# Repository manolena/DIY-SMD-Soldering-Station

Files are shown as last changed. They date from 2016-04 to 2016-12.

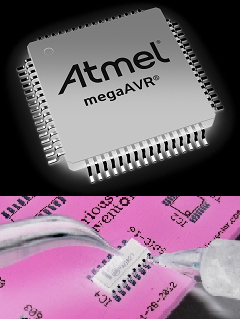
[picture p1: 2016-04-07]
microSD Files/FILE7.bmp

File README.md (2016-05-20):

# DIY-SMD-Soldering-Station
A DIY Soldering Station with ATMega2560 and SMD parts

Many thanks to Matthias <https://debugginglab.wordpress.com/2014/10/30/soldering-station/> for
the inspiration.
There were some improvments to UI with insertion of bargraphs for desired and actual temperature, 
indication for memory saved last desired temperature and settings with rotary endoder instead of
pot.

It would be also a remiss not to thank Stefanos Tselepis FireDeveloper <https://github.com/FireDeveloper> for his
aewosome RGB MultyBit Calculator. It helped a lot for developing code with MCUFRIEND small TFT.

From version IRON_18 and later, the combatible TFT is this:
   http://www.ebay.com/itm/240x320-3-3V-2-4-SPI-TFT-LCD-Touch-Panel-Serial-Port-Module-with-PBC-ILI9341-/171983887298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

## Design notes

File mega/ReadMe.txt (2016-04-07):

For expanding your Arduino's MEGA2560 pins number, you have to copy the file "mega" into your 
C:\arduino-xxx\hardware\arduino\variants directory. Close and re-open the sketch and all changes 
will be energized.

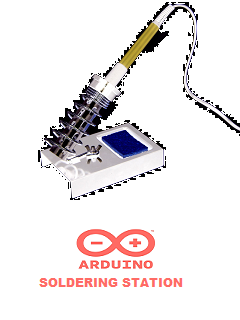
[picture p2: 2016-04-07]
microSD Files/FILE5.bmp

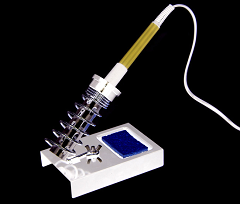
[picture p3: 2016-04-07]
microSD Files/FILE4.bmp

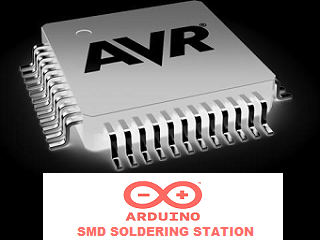
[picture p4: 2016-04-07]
microSD Files/FILE0.bmp

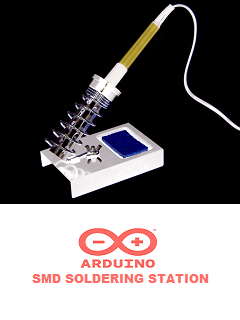
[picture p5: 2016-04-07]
microSD Files/FILE6.bmp

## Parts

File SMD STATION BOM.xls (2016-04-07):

Part List
Source Data From: |  | SMD STATION.PrjPcb
Project: |  | SMD STATION.PrjPcb
Variant: |  | None
Report Date: | 06/04/2016 | 16:29:08
Print Date: | 2016-04-06 | 19:12:58
Designator | Comment | LibRef | Footprint | Description | Link
*1 | HEAT-S1 | HEAT-S1 | SK 104 HEATSHINK |  | http://www.marelectronics.gr/products.php?id=28499&lang=gr
BUZ1 | BUZZER | BUZZER | BUZZER |  | http://www.ebay.com/itm/9mm-Dia-Electronic-Alarm-PCB-Panel-Mounting-Piezo-Buzzer-Sounder-10pcs-/121808580371
C1 | 2200uF/35V | Cap Pol1 | RB5-10.5 | Capacitor, Electrolytic, 2200uF/35V | http://www.acdcshop.gr/capacitorelectrolytic16x25mm105c35v2200uf-p-1131.html?sort=2a
C2, C3, C4, C5, C6 | 100nF | D-101-0085, D-101-0085, Cap, Cap, Cap | 0805 | Capacitor, Ceramic, 100nF 10% 50V 0805 (2012) X7R | http://www.ebay.com/itm/570pcs-57-Value-Kit-0805-SMD-Ceramic-capacitor-1pF-22uF-MLCC-SMT-Assortment-Kit-/161921774228
C7, C8, C9, C10, C11, C14 | 10nF | D-101-0085 | 0805 | Capacitor, Ceramic, 10nF 10% 50V 0805 (2012) X7R | http://www.ebay.com/itm/570pcs-57-Value-Kit-0805-SMD-Ceramic-capacitor-1pF-22uF-MLCC-SMT-Assortment-Kit-/161921774228
C12 | 47nF | D-101-0085 | 0805 | Capacitor, Ceramic, 47nF 10% 50V 0805 (2012) X7R | http://www.ebay.com/itm/570pcs-57-Value-Kit-0805-SMD-Ceramic-capacitor-1pF-22uF-MLCC-SMT-Assortment-Kit-/161921774228
C13 | 10uF/25V | Cap Pol1 | RB-08 | Capacitor, Electrolytic, 10uF/25V | http://www.acdcshop.gr/capacitorelectrolytictht10uf50v2165x11mmpitch2mm20-p-22072.html?sort=2a
D1 | PWR | LED0 | 1206D | LED, Green, 1206 (for PCB), 5mm (for panel) | http://www.ebay.com/itm/120pcs-SMD-SMT-1206-White-Red-Green-Blue-Yellow-Orange-LED-Mix-Super-Bright-Kit-/281638415634
D2 | HEAT | LED0 | 1206D | LED, Red, 1206 (for PCB), 5mm (for panel) | http://www.ebay.com/itm/120pcs-SMD-SMT-1206-White-Red-Green-Blue-Yellow-Orange-LED-Mix-Super-Bright-Kit-/281638415634
J1 | PWR2.5 | PWR2.5 | POWER JACK | Low Voltage Power Supply Connector | http://www.ebay.com/itm/50-pcs-2-Pin-5-5-2-1mm-DC-2-1-SMD-Socket-Jack-Female-PCB-Power-Plug-/251620366426
J2 | PTC+ | CON1_S | CON2 | 5.08mm 2 Pin Connect Terminal Screw Terminal Connector | http://www.banggood.com/20PCS-KF301-2P-5_08mm-2-Pin-Connect-Terminal-Screw-Terminal-Connector-p-1004786.html
J3 | PTC- | CON1_S | CON2 |  | http://www.banggood.com/20PCS-KF301-2P-5_08mm-2-Pin-Connect-Terminal-Screw-Terminal-Connector-p-1004786.html
J4 | + | CON1_S | CON2 | 5.08mm 2 Pin Connect Terminal Screw Terminal Connector | http://www.banggood.com/20PCS-KF301-2P-5_08mm-2-Pin-Connect-Terminal-Screw-Terminal-Connector-p-1004786.html
J5 | STBY_SW | CON1_S | CON2 |  | http://www.banggood.com/20PCS-KF301-2P-5_08mm-2-Pin-Connect-Terminal-Screw-Terminal-Connector-p-1004786.html
J6 | - | CON1_S | CON2 | 5.08mm 2 Pin Connect Terminal Screw Terminal Connector | http://www.banggood.com/20PCS-KF301-2P-5_08mm-2-Pin-Connect-Terminal-Screw-Terminal-Connector-p-1004786.html
J7 | GND | CON1_S | CON2 |  | http://www.banggood.com/20PCS-KF301-2P-5_08mm-2-Pin-Connect-Terminal-Screw-Terminal-Connector-p-1004786.html
J8 | -LED HEAT | CON1_S | CON2 | 5.08mm 2 Pin Connect Terminal Screw Terminal Connector | http://www.banggood.com/20PCS-KF301-2P-5_08mm-2-Pin-Connect-Terminal-Screw-Terminal-Connector-p-1004786.html
J9 | +LED HEAT | CON1_S | CON2 |  | http://www.banggood.com/20PCS-KF301-2P-5_08mm-2-Pin-Connect-Terminal-Screw-Terminal-Connector-p-1004786.html
J10 | +PWR | CON1_S | CON2 | 5.08mm 2 Pin Connect Terminal Screw Terminal Connector | http://www.banggood.com/20PCS-KF301-2P-5_08mm-2-Pin-Connect-Terminal-Screw-Terminal-Connector-p-1004786.html
J11 | -PWR | CON1_S | CON2 |  | http://www.banggood.com/20PCS-KF301-2P-5_08mm-2-Pin-Connect-Terminal-Screw-Terminal-Connector-p-1004786.html
J12, J13 | K-TC | CON1_S | CON2 | 5.08mm 2 Pin Connect Terminal Screw Terminal Connector | http://www.banggood.com/20PCS-KF301-2P-5_08mm-2-Pin-Connect-Terminal-Screw-Terminal-Connector-p-1004786.html
J14, J15 | NTC | CON1_S | CON2 |  | http://www.banggood.com/20PCS-KF301-2P-5_08mm-2-Pin-Connect-Terminal-Screw-Terminal-Connector-p-1004786.html
MD1 | ATMEGA2860 CORE | ATMEGA2560 CORE | ATMEGA 2560 CORE | Mega2560-CORE mini 2560 Arduino | http://www.ebay.com/itm/221502571388
MDL1, MDL2 | STEP DOWN CONVERTER | STEP DOWN CONVERTER | STEP DOWN CONVERTER MINI | Mini DC Adjustable Power Supply Buck Module Step Down Module | http://www.banggood.com/5Pcs-Mini-DC-Adjustable-Power-Supply-Buck-Module-Step-Down-Module-p-952402.html
OP1 | TCMT1100 | OPTO-AC1 | SOP-4 | AC OPTOCUPLER | http://www.ebay.com/itm/30-St-SMD-Optokoppler-TCMT-1100-Vishay-E0671-/400690570408
P1 | ISP | Header 3X2 | HDR2X3 | Header, 3-Pin, Dual row | http://www.ebay.com/itm/10PCS-2-54mm-2-x-40-Pin-Male-Double-Row-Pin-Header-Strip-/130713472733
P2, P3 | Header 13X2 | Header 13X2 | IDC2.54-V26A | Header, 13-Pin, Dual row | http://www.ebay.com/itm/10PCS-2-54mm-2-x-40-Pin-Male-Double-Row-Pin-Header-Strip-/130713472733
Q1 | IRF9530 | PMOS-2 | TO-220V | P-Channel Power MOSFET | http://www.acdcshop.gr/transistorunipolarpmosfet100v12a88wto220ab-p-13376.html?sort=2a
Q2 | BS170 | NMOS-2 | T0-92 | N-Channel Power MOSFET | http://www.ebay.com/itm/10PCS-BS170-MOSFET-N-CH-60V-500MA-TO-92-FSC-NEW-/141739738318
Q3 | MMBTA42 | NPN | SO-G3 | NPN Bipolar Transistor | http://www.ebay.com/itm/100PCS-IC-MMBTA42-SOT-23-TRANSISTOR-NPN-300V-0-5A-Pb-Free-RoHS-SMD-/171538574109
Q4 | MMBTA92 | PNP | SO-G3 | PNP Bipolar Transistor | http://www.ebay.com/itm/100PCS-IC-MMBTA92-SOT-23-TRANSISTOR-NPN-300V-0-5A-Pb-Free-RoHS-SMD-/181583143545
R1, R5, R11, R12, R17 | 1K | Res2, RES, Res2, RES, RES | 0805 | Resistor, Ceramic, 1%, 0805 | http://www.ebay.com/itm/80-Value-0805-SMD-Resistor-Kit-1-10R-910K-80valuesX25pcs-2000pcs-/121614392100
R2, R3, R4, R16, R19 | 10K | RES, Res2, RES, RES, RES | 0805 |  | http://www.ebay.com/itm/80-Value-0805-SMD-Resistor-Kit-1-10R-910K-80valuesX25pcs-2000pcs-/121614392100
R6 | 220K | RES | 0805 |  | http://www.ebay.com/itm/80-Value-0805-SMD-Resistor-Kit-1-10R-910K-80valuesX25pcs-2000pcs-/121614392100
R7 | 220R | Res2 | 0805 |  | http://www.ebay.com/itm/80-Value-0805-SMD-Resistor-Kit-1-10R-910K-80valuesX25pcs-2000pcs-/121614392100
R8 | 15K | RES | 0805 |  | http://www.ebay.com/itm/80-Value-0805-SMD-Resistor-Kit-1-10R-910K-80valuesX25pcs-2000pcs-/121614392100
R9 | 2K2 | RES | 0805 |  | http://www.ebay.com/itm/80-Value-0805-SMD-Resistor-Kit-1-10R-910K-80valuesX25pcs-2000pcs-/121614392100
R10 | 330R | RES | 0805 |  | http://www.ebay.com/itm/80-Value-0805-SMD-Resistor-Kit-1-10R-910K-80valuesX25pcs-2000pcs-/121614392100
R13 | 4K7 | RES | 0805 |  | http://www.ebay.com/itm/80-Value-0805-SMD-Resistor-Kit-1-10R-910K-80valuesX25pcs-2000pcs-/121614392100
R14, R20 | 100K/1% | RES | 0805 |  | http://www.ebay.com/itm/80-Value-0805-SMD-Resistor-Kit-1-10R-910K-80valuesX25pcs-2000pcs-/121614392100
R15, R18 | 24K/1% | RES | 0805 |  | http://www.ebay.com/itm/80-Value-0805-SMD-Resistor-Kit-1-10R-910K-80valuesX25pcs-2000pcs-/121614392100
R21 | 10K/1% | RES | 0805 |  | http://www.ebay.com/itm/80-Value-0805-SMD-Resistor-Kit-1-10R-910K-80valuesX25pcs-2000pcs-/121614392100
R22 | 5K | RPot2 | VR6 | 3296W Multiturn Trimmer Resistance Potentiometer Kit | http://www.banggood.com/50Pcs-3296W-Multiturn-Trimmer-Resistance-Potentiometer-Kit-p-969193.html
R23 | 120K | RES | 0805 | 'Resistor, Ceramic, 1%, 0805 | http://www.ebay.com/itm/80-Value-0805-SMD-Resistor-Kit-1-10R-910K-80valuesX25pcs-2000pcs-/121614392100
R24 | 100K | RPot2 | VR6 | 3296W Multiturn Trimmer Resistance Potentiometer Kit | http://www.banggood.com/50Pcs-3296W-Multiturn-Trimmer-Resistance-Potentiometer-Kit-p-969193.html
S1 | SW-SPST | SW-SPST | SPST-2 | Single-Pole, Single-Throw Switch | http://www.acdcshop.gr/switchtoggle2positionspdtonon3a250vac5524785c20m-p-21899.html
S2 | SW DIP-4 | SW DIP-4 | DIP-8 | DIP Switch, 4 Position, SPST | http://www.acdcshop.gr/switchdipswitchpolesnumber4onoff01a24vdc2524770c-p-19100.html
SW1 | ENCODER | ROTARY ENC | HDR1X5 |  | http://www.banggood.com/5Pcs-5V-KY-040-Rotary-Encoder-Module-For-Arduino-AVR-PIC-p-951151.html
TFT1 | 2.4 | 2.4 TFT SHIELD MCUFRIEND | ARDUINO UNO |  | http://www.banggood.com/UNO-R3-ATmega328P-Board-2_4-Inch-TFT-LCD-Screen-Module-For-Arduino-p-945755.html
U1, U2 | LT1013 | LT1013ACJ8 | DIP-8 | Dual Precision Operational Amplifier | http://www.acdcshop.gr/operationalamplifierdip8-p-24732.html?sort=2a
U3 | LM336 | LM336Z | Z03A | Adjustable Micropower Voltage Reference | http://www.marelectronics.gr/products.php?id=2545&lang=gr
 |  |  |  | Soldering Iron Gun Hot Iron Replacement Solder Station Repair Tool | http://www.banggood.com/Soldering-Iron-Gun-Hot-Iron-Replacement-Solder-Station-Repair-Tool-p-87173.html
 |  |  |  | Κουτί Τροφοδοτικού - Enclosure ABS for power supply 190x110x75 snapsScrews | http://www.acdcshop.gr/enclosureabsforpowersupply190x110x75snapsscrews-p-7487.html

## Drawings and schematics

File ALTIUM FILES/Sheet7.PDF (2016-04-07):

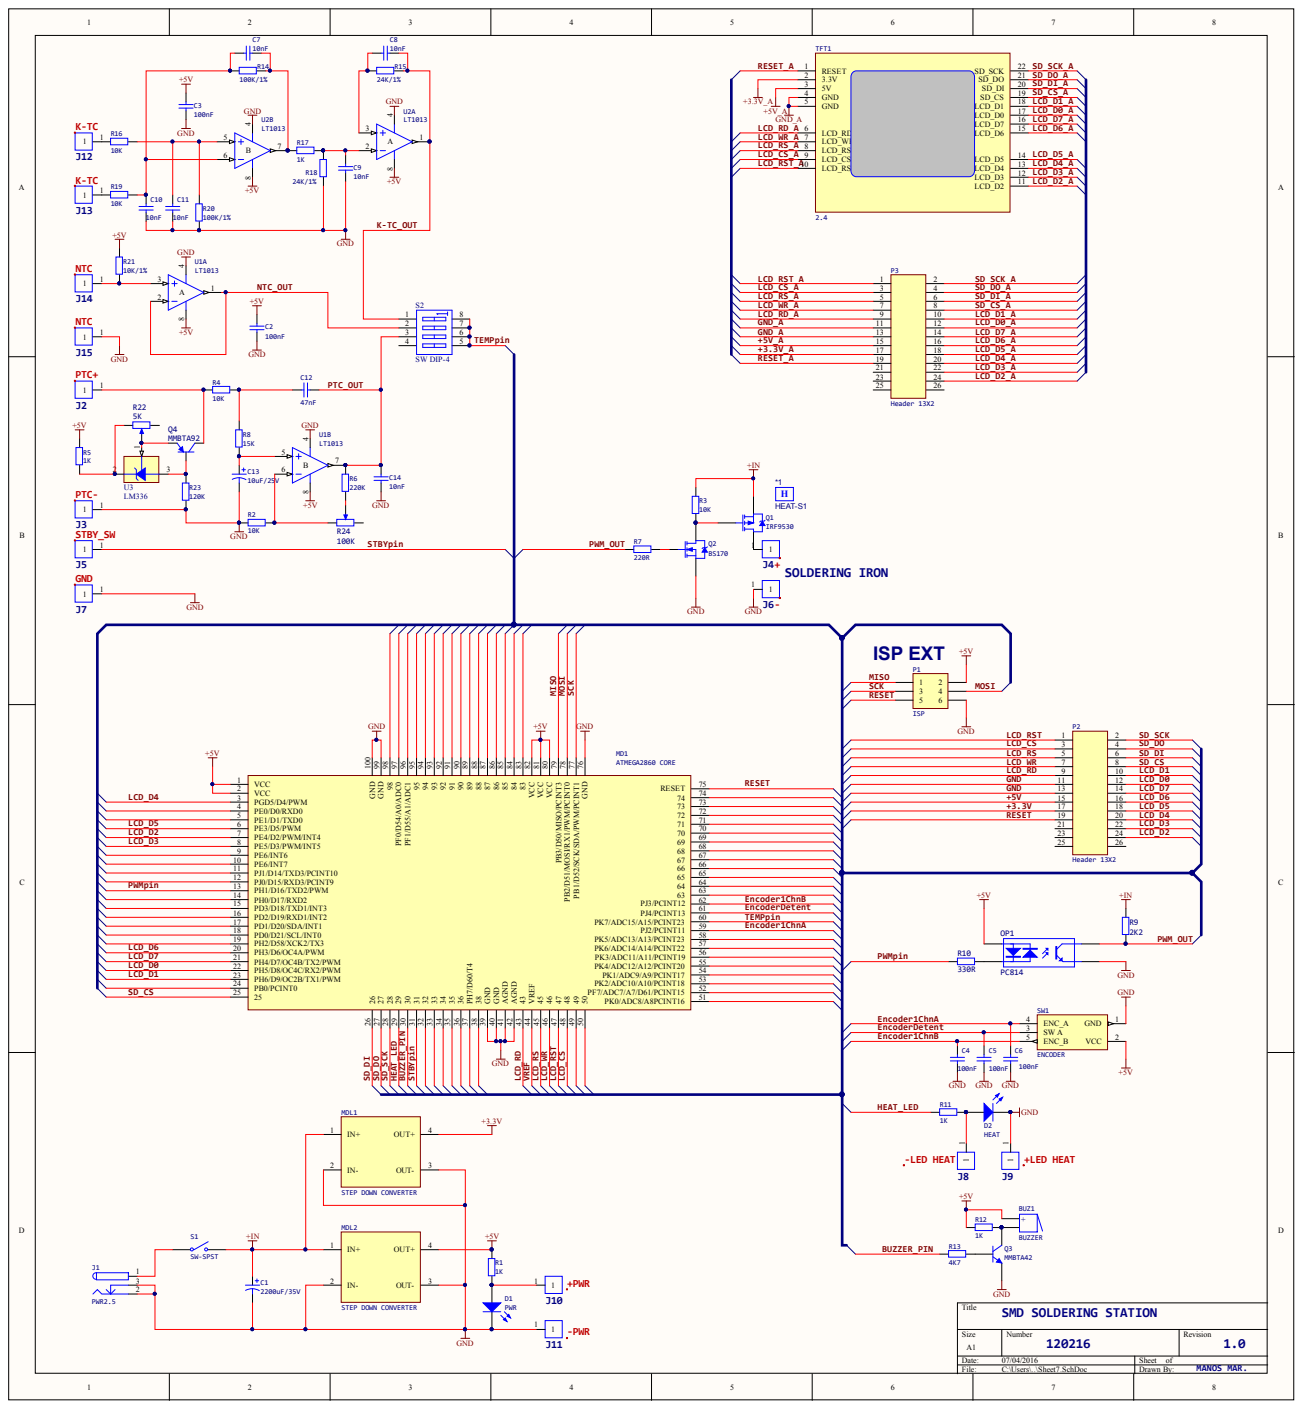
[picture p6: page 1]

GND 76 PB1/D52/SCK/SDA/PWM/PCINT1 77 PB2/D51/MOSI/RX1/PWM/PCINT0 78 PB3/D50/MISO/PCINT3 79 VCC 80 VCC 81 VCC 82 83 83 84 84 85 85 86 86 87 87 88 88 89 89 90 90 91 91 92 92 93 93 94 94 95 95 PF1/D55/A1/ADC1 96 PF0/D54/A0/ADC0 97 98 98 GND 99 GND 100

Date: 07/04/2016 | Sheet of
File: C:\Users\..\Sheet7.SchDoc | Drawn By: MANOS MAR.

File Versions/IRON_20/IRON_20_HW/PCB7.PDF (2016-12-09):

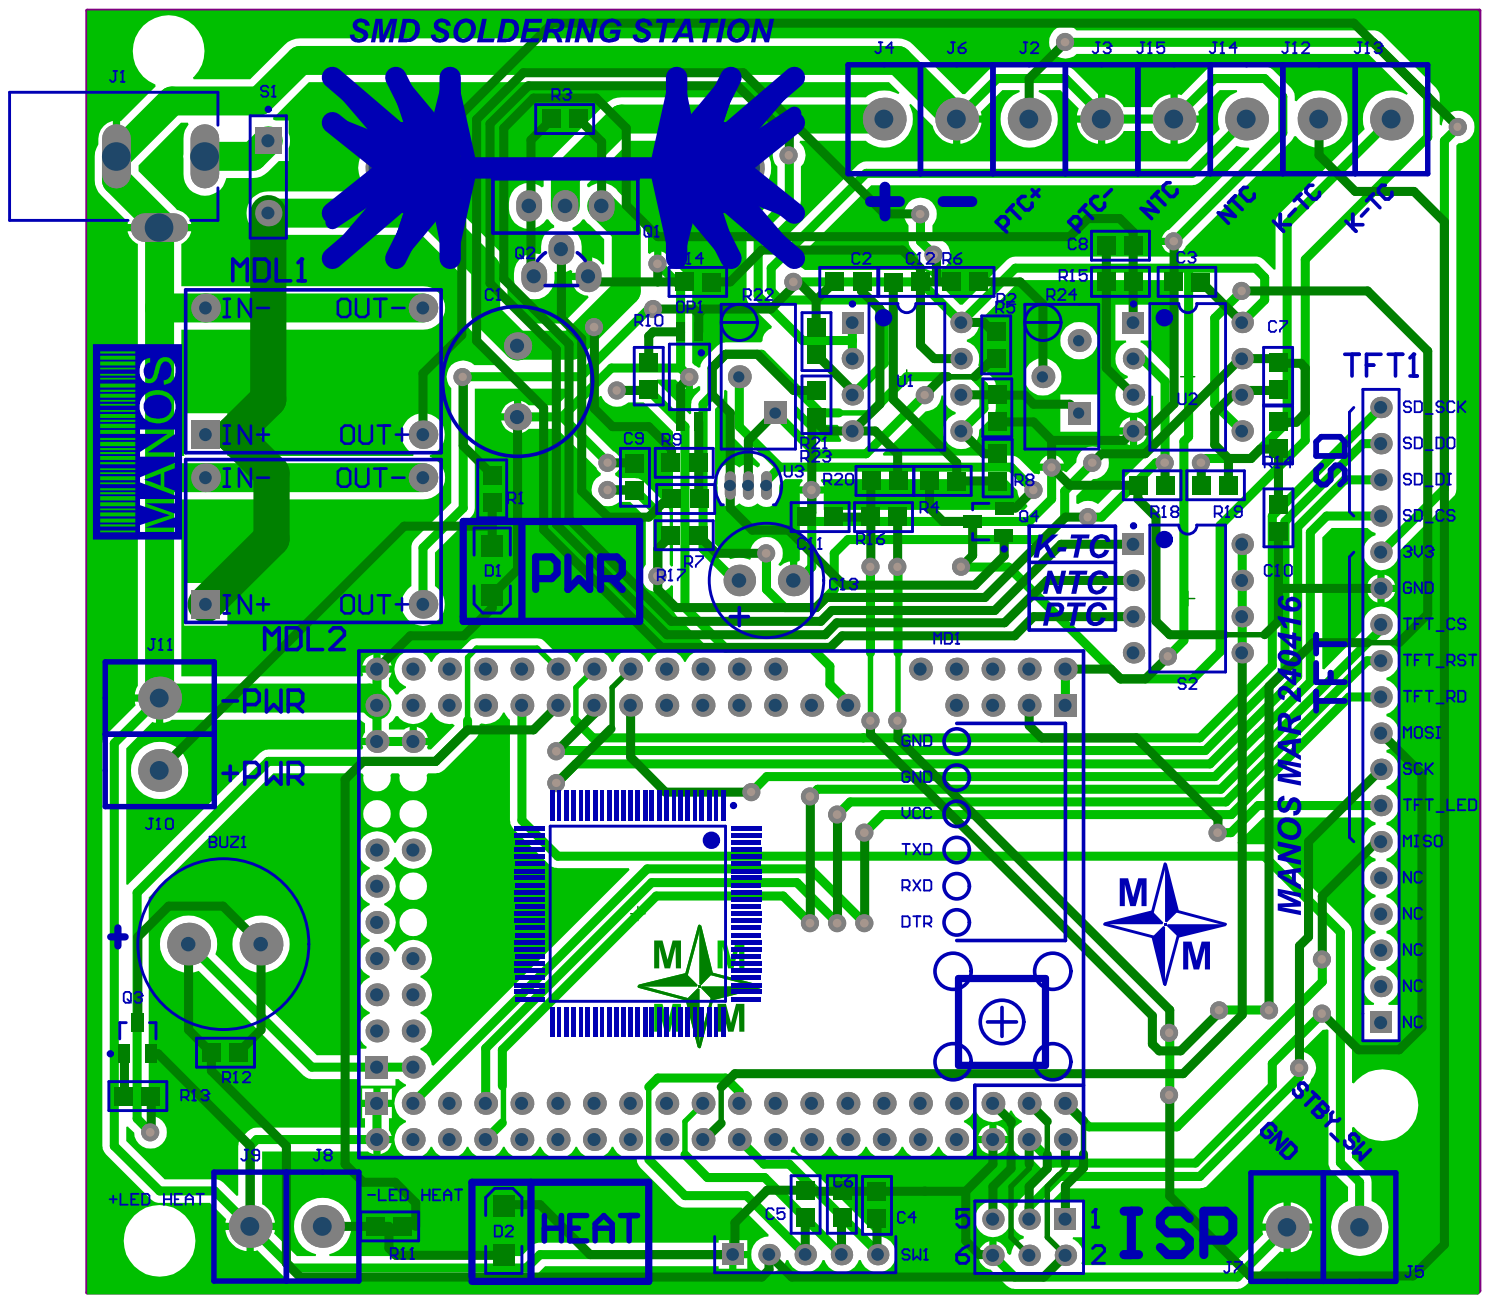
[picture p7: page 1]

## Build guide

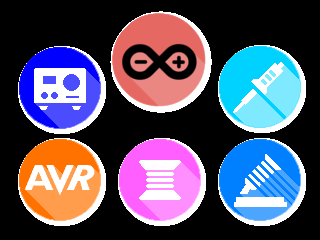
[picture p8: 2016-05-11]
microSD Files/SolderingStation2.bmp

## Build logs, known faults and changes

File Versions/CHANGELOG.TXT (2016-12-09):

11APR2016: The latest version is now IRON_18 and firmware version is 1.5

1. Added iron holder with in-built "Iron in parking position" capability. The actual temperature automatically drops 
    down to 175°C if desired temperature is > 175°C and the iron is in parking position.
2. Added "unplugged iron" function: when device is unplugged, a message appears on the screen until it is plugged
    back again.
3. Added "click sound" when encoder is rotating.    
4. Combatible TFT for this version is this: 
   http://www.ebay.com/itm/240x320-3-3V-2-4-SPI-TFT-LCD-Touch-Panel-Serial-Port-Module-with-PBC-ILI9341-/171983887298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
   
09DEC2016: The latest version is now IRON_20 and firmware version is 1.6
1. Added backlight for TFT on D4

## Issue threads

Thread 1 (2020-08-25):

DIY-SMD-焊接台

JHS1211, 2020-08-25:
Hello, this soldering station is gorgeous, ask you a question, the soldering station can connect JBC - T245 heater? If you can, how to connect? Thank you very much.

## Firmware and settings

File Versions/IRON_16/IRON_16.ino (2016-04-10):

#include <Adafruit_GFX.h>    // Core graphics library
#include <Adafruit_TFTLCD.h> // Hardware-specific library
#include <SPI.h>
#include <SD.h>
#include <EEPROMEx.h>
#include <Encoder1.h>
#include <PinChangeInt.h>
#include <TimerOne.h>
#include <PID_v1.h>
//=======================================================================
#define MCUFRIENT_2_4_TFT  0x9341

#if defined (__AVR_ATmega2560__) || (__AVR_ATmega1280__)
#define SD_CS                 10     // Set the chip select line to whatever you use (10 doesnt conflict with the library)
#define SD_SCK                13
#define SD_MISO               12
#define SD_MOSI               11
#endif

#define LCD_CS                A3 // Chip Select goes to Analog 3
#define LCD_CD                A2 // Command/Data goes to Analog 2
#define LCD_WR                A1 // LCD Write goes to Analog 1
#define LCD_RD                A0 // LCD Read goes to Analog 0
#define LCD_RESET             A4 // Can alternately just connect to Arduino's reset pin

#define STANDBYin             47
#define TEMPin 	              A15
#define PWMpin 	              16

#define Encoder1ChnA          78
#define Encoder1ChnB          77
#define EncoderDetent         79

#define BUZZER_PIN            48
#define HEAT_LED              49

#define OFF		      0
#define ON		      1


// 16-bit color values:
#define BLACK           0x0000      /*   0,   0,   0 */
#define NAVY            0xFFF0      /*   0,   0, 128 */
#define DARKGREEN       0xFC1F      /*   0, 128,   0 */
#define DARKCYAN        0xFC10      /*   0, 128, 128 */
#define MAROON          0x7800      /* 128,   0,   0 */
#define PURPLE          0x780F      /* 128,   0, 128 */
#define OLIVE           0x7BE0      /* 128, 128,   0 */
#define LIGHTGREY       0xC618      /* 192, 192, 192 */
#define DARKGREY        0x7BEF      /* 128, 128, 128 */
#define BLUE            0x001F      /*   0,   0, 255 */
#define GREEN           0x07E0      /*   0, 255,   0 */
#define CYAN            0x07FF      /*   0, 255, 255 */
#define RED             0xF800      /* 255,   0,   0 */
#define MAGENTA         0xF81F      /* 255,   0, 255 */
#define YELLOW          0x07FF      /* 255, 255,   0 */
#define WHITE           0xFFFF      /* 255, 255, 255 */
#define ORANGE          0xFD20      /* 255, 165,   0 */
#define GREENYELLOW     0xAFE5      /* 173, 255,  47 */
#define PINK            0xF81F

#define ANGLE_0    0
#define ANGLE_90   1
#define ANGLE_180  2
#define ANGLE_270  3

#define VERSION "v1.5"		
#define INTRO

#define DELAY_MAIN_LOOP 	500//150
#define DELAY_MEASURE 		2

#define ADC_TO_TEMP_GAIN 	1.8//0.99//2.50//0.53 //0.415
#define ADC_TO_TEMP_OFFSET      25.0
#define STANDBY_TEMP		175
#define MAX_TEMP		400
#define MIN_TEMP	        25 // Minimum setpoint temperature

#define MAX_PWM_LOW		180//180
#define MAX_PWM_HI		220//210		

#define PWM_DIV                 1024		

#define WILL_TEMP_EEPROM_ADDRESS 0x10
#define ENCODER_EEPROM_ADDRESS   0x20

// Auto turn-off time (in milliseconds)
#define TURN_OFF_TIME 1800000    //30min  1800000

//#define DEBUG_SER
#define BARGRAPHS

double Setpoint, Input, Output;

//Define the aggressive and conservative Tuning Parameters
//double aggKp=0.5, aggKi=0.9, aggKd=0.2;
//double consKp=0.5, consKi=0.9, consKd=0.2;


double aggKp=450, aggKi=260, aggKd=200;
double consKp=450, consKi=260, consKd=200;

//=======================================================================
int pwm = 0; //pwm Out Val 0.. 255
int actual_temperature, will_temp = STANDBY_TEMP;

boolean standby_act = false;
int tempDIV;
float encoderValue = 0;
volatile float encoderPos = 0;
volatile float encoderPosTemp = 0;
volatile boolean PastA = 0;
volatile boolean PastB = 0;
boolean memWrite = false;
boolean memNoWrite = true;
boolean state = false;
boolean heater = false;
boolean unplug = 0;
int t1,t2;
static boolean rotating = false;
const int numReadings = 150;//30
int readings[numReadings];      // the readings from the analog input
int readIndex = 0;              // the index of the current reading
int total = 0;                  // the running total
float adcValue;

long update_last, on_time = 0;
char heater_mode = OFF;

//=======================================================================
Adafruit_TFTLCD tft(LCD_CS, LCD_CD, LCD_WR, LCD_RD, LCD_RESET);
Encoder1 myEncoder = Encoder1(Encoder1ChnA,Encoder1ChnB,EncoderDetent);
PID myPID(&Input, &Output, &Setpoint, consKp, consKi, consKd, DIRECT);
//=======================================================================
void setup(void) 
{ 
  Serial.begin(9600); 
  pinMode(PWMpin, OUTPUT);
  setPwmFrequency(PWMpin, PWM_DIV);
  digitalWrite(PWMpin, HIGH); 
  for (int thisReading = 0; thisReading < numReadings; thisReading++) 
  {
    readings[thisReading] = 0;
  }  
  tft.reset();
  tft.begin(MCUFRIENT_2_4_TFT);
  tft.setRotation(ANGLE_270);//
  Serial.println(F("TFT Reset."));
  delay(10);

  pinMode(STANDBYin, INPUT_PULLUP);

  pinMode(TEMPin, INPUT);
  digitalWrite(TEMPin, LOW);  

  pinMode(BUZZER_PIN, OUTPUT);
  digitalWrite(BUZZER_PIN, LOW); 
  beepBuzzer(6250,250);  

  pinMode(HEAT_LED, OUTPUT);
  digitalWrite(HEAT_LED, LOW);   

  pinMode(Encoder1ChnA, INPUT); 
  digitalWrite(Encoder1ChnA, HIGH); //turn pullup resistor on
  pinMode(Encoder1ChnB, INPUT); 
  digitalWrite(Encoder1ChnB, HIGH); //turn pullup resistor on
  pinMode(EncoderDetent, INPUT); 
  digitalWrite(EncoderDetent, HIGH); //turn pullup resistor on 

  PCintPort::attachInterrupt(Encoder1ChnA, &updateEncoder_ISR, CHANGE); 
  PCintPort::attachInterrupt(Encoder1ChnB, &updateEncoder_ISR, CHANGE);
  PCintPort::attachInterrupt(EncoderDetent, &EncoderClick_ISR, FALLING);
  myEncoder.setRate(1.0f);
  myEncoder.setMinMax(MIN_TEMP,MAX_TEMP); 

  Timer1.initialize(150000); // set a timer of length 100000 microseconds (or 0.1 sec - or 10Hz => the led will blink 5 times, 5 cycles of on-and-off, per second)
  Timer1.attachInterrupt( timer1_ISR ); // attach the service routine here  

  Serial.println(F("Initializing SD card..."));
#if defined (__AVR_ATmega2560__) || (__AVR_ATmega1280__)
  if (!SD.begin(SD_CS, SD_MOSI, SD_MISO, SD_SCK )) 
  {
    Serial.println(F("Initialization failed!"));
    return;
  }
#else
  if (!SD.begin(SD_CS)) 
  {
    Serial.println(F("Initialization failed!"));
    return;
  }
#endif

  Serial.println("Sketch'es location:");
  Serial.println("C:\\Users\\Administrator\\Documents\\DXP\\AVR SOLDERING IRON\\FIRMWARE\\IRON_15");

  Serial.println(F("Initialization done."));
  delay(500);

  SPI.setClockDivider(SPI_CLOCK_DIV4);  // 4MHz 

  tft.fillScreen(tft.color565(255,255,255));//BLACK  
  //  bmpDraw("FILE0.bmp", 0, 0);
  //  delay(2000);

  mainScreen();  

  will_temp = EEPROM.readInt(WILL_TEMP_EEPROM_ADDRESS);
  myEncoder.setPosition(will_temp);

  if (will_temp == 4294967295) 
  {
    will_temp = STANDBY_TEMP;
  }
  encoderPos = EEPROM.readInt(ENCODER_EEPROM_ADDRESS);
  if (encoderPos == 4294967295) 
  {    
    myEncoder.setPosition(will_temp);
  }
  actual_temperature = will_temp;
  //  myEncoder.setPosition(MAX_TEMP-2);
  //  encoderPos = MAX_TEMP-2;
#if defined BARGRAPHS  
  verticalBar();
  horizontalBar();
#endif 
  Input = getTemperature()-ADC_TO_TEMP_OFFSET;
  Setpoint = ADC_TO_TEMP_OFFSET;
  myPID.SetMode(AUTOMATIC);
  heater_mode = ON;
  pwm = 0;
}
//=======================================================================
void mainScreen ()
{
  tft.fillScreen(tft.color565(255,255,255));//BLACK    
  tft.setTextSize(2);
  tft.setTextColor(tft.color565(0,255,255));//RED
  tft.setCursor(260,5);
  tft.print(VERSION);
  tft.setTextColor(tft.color565(255,255,0));//BLUE
  tft.setCursor(258,3);
  tft.print(VERSION);

  tft.setTextColor(BLACK);
  tft.setTextSize(2);
  tft.setCursor(3,57);
  tft.print("TIP");
  tft.setCursor(3,78);
  tft.print("TEMP:");
  tft.setCursor(228,28);
  tft.setTextColor(tft.color565(tempDIV, tempDIV-255, 255-tempDIV));
  tft.print("o");

  tft.setTextColor(tft.color565(255,0,255));
  tft.setCursor(3,143);
  tft.print("SET:");
  tft.setCursor(228,93);
  tft.print("o");

  tft.setTextColor(tft.color565(0,255,255));
  tft.setCursor(3,183);
  tft.print("PWM:");
  tft.setCursor(228,183);
  tft.print("%"); 

  int tempWill = EEPROM.readInt(WILL_TEMP_EEPROM_ADDRESS);
  myEncoder.setPosition(tempWill);
  tft.setTextColor(tft.color565(255,0,255));  //GREEN  
  tft.setTextSize(2);
  tft.setCursor(100,7);
  tft.print("*MEM = ");
  tft.print(tempWill);
  tft.setTextSize(1);
  tft.print(" o"); 
  tft.setTextSize(2);
  tft.print("C    "); 
#if defined BARGRAPHS  
  verticalBar();
  horizontalBar();
#endif   
}  
//=======================================================================
void loop()
{  
  int MAX_PWM;
  // Automatic turn-off
  if((millis() - on_time) >= TURN_OFF_TIME) 
  {
    tft.fillScreen(tft.color565(255,255,255));//BLACK
    heater_mode = OFF;   
    do
    {        
      analogWrite(PWMpin, 0);
      pwm = 0;
      tft.setTextColor(tft.color565(0,255,255));
      tft.setTextSize(5);
      tft.setCursor(5,80);
      tft.print("SHUT DOWN!");
      heater = LOW;
    }
    while(heater_mode == OFF);
    mainScreen();   
  }

  Input = getTemperature()-ADC_TO_TEMP_OFFSET;
  Setpoint = encoderPos;
  double gap = abs(Setpoint-Input); //distance away from setpoint
  if(gap < 10)
  {  //we're close to setpoint, use conservative tuning parameters
    myPID.SetTunings(consKp, consKi, consKd);
  }
  else
  {
    //we're far from setpoint, use aggressive tuning parameters
    myPID.SetTunings(aggKp, aggKi, aggKd);
  }
  myPID.Compute();
  
  pwm = Output;
  MAX_PWM = actual_temperature <= STANDBY_TEMP ? MAX_PWM_LOW : MAX_PWM_HI;
  pwm = pwm > MAX_PWM ? pwm = MAX_PWM : pwm < 0 ? pwm = 0 : pwm;
  analogWrite(PWMpin, pwm);

  if(pwm != 0)
  {
    heater = HIGH;
    tft.fillCircle(150, 190, 11, tft.color565(0,255,255));
  }
  else 
  {    
    heater = LOW;
    tft.fillCircle(150, 190, 11, tft.color565(255,255,255));
  }   
  writeHEATING(will_temp, Input, pwm);
  //delay(DELAY_MAIN_LOOP);		//wait for some time  

  static boolean oneTime = false; 

  will_temp = map(encoderPos, MIN_TEMP, MAX_TEMP, MIN_TEMP, MAX_TEMP);

  int tempWill = EEPROM.readInt(WILL_TEMP_EEPROM_ADDRESS);
  tft.setTextSize(3);  

  if (digitalRead(STANDBYin) == true)
  {
    tft.setCursor(2,2);
    if(oneTime)
    {      
      tft.fillRect(2, 2, 80, 40, tft.color565(255,255,255));
      beepBuzzer(6250,80);
      oneTime = false; 
    }     
    tft.setTextColor(tft.color565(255,0,255));//GREEN
    tft.print("OPP ");
  }  
  else
  {
    tft.setCursor(2,2);
    if(!oneTime)
    {
      tft.fillRect(2, 2, 80, 40, tft.color565(255,255,255));
      beepBuzzer(6250,80);
      oneTime = true;
    }
    tft.setTextColor(tft.color565(0,255,255));
    tft.print("STBY");
  }

  if((memNoWrite == true) && (memWrite = false))
  {    
    tft.setTextColor(tft.color565(255,255,255));    
    memNoWrite = true; 
    memWrite = false; 
  }  
  else if((memNoWrite == false) && (memWrite = true))
  {
    tft.fillRect(90, 2, 170, 20, tft.color565(255,255,255));
    tft.setTextColor(tft.color565(255,0,255));  //GREEN  
    tft.setTextSize(2);
    tft.setCursor(100,7);
    tft.print("*MEM = ");   
    tft.print(tempWill);
    tft.setTextSize(1);
    tft.print(" o"); 
    tft.setTextSize(2);
    tft.print("C    ");
  }

  memNoWrite = true; 
  memWrite = false; 

  int will_temp_tmp = will_temp;

  if (digitalRead(STANDBYin) == false)
    standby_act = true;
  else
    standby_act = false;

  if (standby_act && (will_temp >= STANDBY_TEMP ))
    will_temp_tmp = STANDBY_TEMP;  

  actual_temperature = getTemperature();
  if(actual_temperature > MAX_TEMP+100)
  {    
    pwm = 0;
    digitalWrite(HEAT_LED, LOW);
    actual_temperature = 0; 
    tft.fillScreen(tft.color565(255,255,255));//BLACK
    tft.setTextColor(tft.color565(0,255,255));
    tft.setTextSize(5);
    tft.setCursor(5,80);
    do
    {      
      tft.print("UNPLUGGED!");
      delay(200);
      actual_temperature = getTemperature();
    }
    while(actual_temperature > MAX_TEMP+50);
    
    mainScreen();

    tft.setTextSize(7);
    tft.setCursor(100,108);
    tft.setTextColor(tft.color565(255,0,255));//===========================>>>>>>>>>>>>>>>>>>>>>
    if (t2 < 100)
      tft.print(" ");
    if (t2 <10)
      tft.print(" ");
    tft.print(t2);
  }
//  delay(DELAY_MAIN_LOOP);
}
//=======================================================================
int getTemperature()
{  
  digitalWrite(PWMpin, 0);		//switch off heater
  delay(DELAY_MEASURE);			//wait for some time (to get low pass filter in steady state)

  total = total - readings[readIndex];
  readings[readIndex] = analogRead(TEMPin);
  total = total + readings[readIndex];
  readIndex = readIndex + 1;

  if (readIndex >= numReadings) 
  {
    readIndex = 0;
  }
  adcValue = total / numReadings;
  analogWrite(PWMpin, pwm);	//switch heater back to last value
  return round(((float) adcValue)*ADC_TO_TEMP_GAIN+ADC_TO_TEMP_OFFSET); //apply linear conversion to actual temperature
}
//=======================================================================
void horizontalBar()
{
  for(int i = 0; i <= 4; i++)
  {
    tft.drawFastVLine(i*60, 220, 10, tft.color565(255,0,255));
  }
  tft.drawBargraphHor(0, 207, 241, 14, MAX_TEMP, will_temp, tft.color565(255,0,255), tft.color565(255,255,255));
  tft.setCursor(5,230);
  tft.setTextColor(tft.color565(255,0,255));
  tft.setTextSize(1);
  tft.print("0");
  tft.setCursor(65,230);
  tft.print("100");
  tft.setCursor(125,230);
  tft.print("200");
  tft.setCursor(185,230);
  tft.print("300");
  tft.setCursor(245,230);
  tft.print("400");       
}  
//=======================================================================
void verticalBar()
{
  for(int i = 1; i <= 5; i++)
  {
    tft.drawFastHLine(282, i*43+6, 14, tft.color565(tempDIV, tempDIV-255, 255-tempDIV));
  }    
  tft.drawBargraphVer(270, 49, 14, 173, MAX_TEMP, t1, tft.color565(tempDIV, tempDIV-255, 255-tempDIV), tft.color565(255,255,255));//DO NOT TOUCH!
  tft.setCursor(290,55);
  tft.setTextSize(1);
  tft.setTextColor(tft.color565(tempDIV, tempDIV-255, 255-tempDIV));
  tft.print("400");
  tft.setCursor(290,98);
  tft.print("300");
  tft.setCursor(290,141);
  tft.print("200");
  tft.setCursor(290,184);
  tft.print("100");
  tft.setCursor(290,227);
  tft.print("0");      
}  
//=======================================================================
void writeHEATING(int tempWILL, int tempVAL, int pwmVAL)
{
  static int d_tempWILL = 1;//2		
  static int tempWILL_OLD = 1;//10
  static int tempVAL_OLD = 1;//10
  static int pwmVAL_OLD	= 1;//10

  pwmVAL = map(pwmVAL, 0, 255, 0, 99);

  tft.setTextSize(7);
  if (tempVAL_OLD != tempVAL)
  {
    tft.setCursor(100,40);
    tft.setTextColor(WHITE);

    if ((tempVAL_OLD/100) != (tempVAL/100))
    {
      tft.print(tempVAL_OLD/100);
    }
    else
      tft.print(" ");

    if ( ((tempVAL_OLD/10)%10) != ((tempVAL/10)%10) )
      tft.print((tempVAL_OLD/10)%10 );
    else
      tft.print(" ");

    if ( (tempVAL_OLD%10) != (tempVAL%10) )
      tft.print(tempVAL_OLD%10 );

    tft.setCursor(100,40);
    tft.setTextColor(BLACK);

    if (tempVAL < 100)
      tft.print(" ");
    if (tempVAL <10)
      tft.print(" ");

    tempDIV = round(float(tempWILL - tempVAL) * 8.5);
    tempDIV = tempDIV > 254 ? tempDIV = 254 : tempDIV < 0 ? tempDIV = 0 : tempDIV;
    tft.setTextColor(tft.color565(tempDIV, tempDIV-255, 255-tempDIV));//===========================>>>>>>>>>>>>>>>>>>>>>

    if (standby_act)
    {
      tft.setTextColor(tft.color565(0,255,255));//===========================>>>>>>>>>>>>>>>>>>>>>
    }

    tft.print(tempVAL); 
    t1 = tempVAL;

    tft.setTextSize(2);
    tft.setCursor(228,28);
    tft.setTextColor(tft.color565(tempDIV, tempDIV-255, 255-tempDIV));
    tft.print("o");
#if defined BARGRAPHS
    verticalBar();
#endif    
    tempVAL_OLD = tempVAL; 
  }

  if ((tempWILL_OLD+d_tempWILL < tempWILL) || (tempWILL_OLD-d_tempWILL > tempWILL))
  {
    tft.setTextSize(7);
    tft.setCursor(100,108);
    tft.setTextColor(WHITE);

    if ((tempWILL_OLD/100) != (tempWILL/100))
    {
      tft.print(tempWILL_OLD/100);
    }
    else
      tft.print(" ");

    if ( ((tempWILL_OLD/10)%10) != ((tempWILL/10)%10) )
      tft.print((tempWILL_OLD/10)%10 );
    else
      tft.print(" ");

    if ( (tempWILL_OLD%10) != (tempWILL%10) )
      tft.print(tempWILL_OLD%10 );

    tft.setCursor(100,108);
    tft.setTextColor(tft.color565(255,0,255));//===========================>>>>>>>>>>>>>>>>>>>>>
    if (tempWILL < 100)
      tft.print(" ");
    if (tempWILL <10)
      tft.print(" ");

    tft.print(tempWILL);
    t2 = tempWILL;
#if defined BARGRAPHS    
    horizontalBar();
#endif    
    tempWILL_OLD = tempWILL;
  }

  tft.setTextSize(3);
  if (pwmVAL_OLD != pwmVAL)
  {
    tft.setCursor(170,178);
    tft.setTextColor(WHITE); 

    if ((pwmVAL_OLD/100) != (pwmVAL/100))
    {
      tft.print(pwmVAL_OLD/100);
    }
    else
      tft.print(" ");

    if ( ((pwmVAL_OLD/10)%10) != ((pwmVAL/10)%10) )
      tft.print((pwmVAL_OLD/10)%10 );
    else
      tft.print(" ");

    if ( (pwmVAL_OLD%10) != (pwmVAL%10) )
      tft.print(pwmVAL_OLD%10 );

    tft.setCursor(170,178);
    tft.setTextColor(tft.color565(0,255,255));//RED
    if (pwmVAL < 100)
      tft.print(" ");
    if (pwmVAL <10)
      tft.print(" ");

    tft.print(pwmVAL);
    pwmVAL_OLD = pwmVAL;
    /*
    if(pwmVAL_OLD != 0)
     {
     //bmpDraw("FILE9.bmp", 130, 167);
     //      digitalWrite(HEAT_LED,HIGH); 
     tft.fillCircle(150, 300, 11, tft.color565(0,255,255));
     }
     else 
     {
     //bmpDraw("FILE10.bmp", 130, 167);
     //      digitalWrite(HEAT_LED,LOW); 
     tft.fillCircle(150, 300, 11, tft.color565(255,255,255));
     } 
     */
  }  
}
//=======================================================================
void beepBuzzer(unsigned long hz, unsigned long ms) 
{ 
  unsigned long us = (750000 / hz);  
  unsigned long rep = (ms * 500L) / us; 

  for (int i = 0; i < rep; i++) 
  {  
    digitalWrite(BUZZER_PIN, HIGH);  
    delayMicroseconds(us);  
    digitalWrite(BUZZER_PIN, LOW);  
    delayMicroseconds(us);  
  }
}
//=======================================================
void updateEncoder_ISR() 
{
  myEncoder.lowLevelTick();
  encoderPos = myEncoder.getPosition();
  heater_mode = ON;
  on_time = millis();
  
  if(encoderPos <= MIN_TEMP)
  {
    myEncoder.setPosition(MIN_TEMP);
    encoderPos = MIN_TEMP;
  }  
  if(encoderPos >= MAX_TEMP) 
  {
    myEncoder.setPosition(MAX_TEMP);//1150
    encoderPos = MAX_TEMP;
  }
  beepBuzzer(6250,1);
}
//=======================================================
void EncoderClick_ISR() 
{  
  myEncoder.lowLevelClick();
  {
    EEPROM.writeInt(WILL_TEMP_EEPROM_ADDRESS, will_temp);
    EEPROM.writeInt(ENCODER_EEPROM_ADDRESS, encoderPos);
    myEncoder.setPosition(encoderPos);
    memWrite = true;
    memNoWrite = false;  
    beepBuzzer(6250,80);
  }  
}
//=======================================================
void timer1_ISR()
{
  Timer1.detachInterrupt();
  state =!state;
  switch(heater)
  {
  case HIGH:
    digitalWrite(HEAT_LED, state);
    break;
  case LOW:
    digitalWrite(HEAT_LED, LOW);
    break;  
  }  
  Timer1.attachInterrupt( timer1_ISR );
}
//=======================================================
void setPwmFrequency(int pin, int divisor) 
{
  byte mode;
  if(pin == 5 || pin == 6 || pin == 9 || pin == 10) 
  {
    switch(divisor) {
    case 1: 
      mode = 0x01; 
      break;
    case 8: 
      mode = 0x02; 
      break;
    case 64: 
      mode = 0x03; 
      break;
    case 256: 
      mode = 0x04; 
      break;
    case 1024: 
      mode = 0x05; 
      break;
    default: 
      return;
    }
    if(pin == 5 || pin == 6) {
      TCCR0B = TCCR0B & 0b11111000 | mode;
    } 
    else {
      TCCR1B = TCCR1B & 0b11111000 | mode;
    }
  } 
  else if(pin == 3 || pin == 11) 
  {
    switch(divisor) 
    {
    case 1: 
      mode = 0x01; 
      break;
    case 8: 
      mode = 0x02; 
      break;
    case 32: 
      mode = 0x03; 
      break;
    case 64: 
      mode = 0x04; 
      break;
    case 128: 
      mode = 0x05; 
      break;
    case 256: 
      mode = 0x06; 
      break;
    case 1024: 
      mode = 0x7; 
      break;
    default: 
      return;
    }
    TCCR2B = TCCR2B & 0b11111000 | mode;
  }
}
//=======================================================================
#define BUFFPIXEL 20
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

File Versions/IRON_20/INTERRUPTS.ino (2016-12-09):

//=======================================================================
// SMD Soldering Station with AVR
// (c) 2016 Manos Mar <manolena2001@gmail.com>, https://manolena.wordpress.com/2015/12/28/diy-smd-soldering-station-with-avr/
// (c) 2014 Martin Kumm http://www.martin-kumm.de/wiki/doku.php?id=Projects:SMD_Solderstation/
// (c) 2014 MatthiasW  https://debugginglab.wordpress.com/2014/10/30/soldering-station/
//=======================================================================
//    INTERRUPT SERVICE ROUTINES
//=======================================================================
//    ENCODER ISR
//=======================================================================
void updateEncoder_ISR() 
{
  myEncoder.lowLevelTick(5,1);//myEncoder.lowLevelTick();
  encoderPos = myEncoder.getPosition();
  if(encoderPos <= MIN_TEMP)
  {
    myEncoder.setPosition(MIN_TEMP);
    encoderPos = MIN_TEMP;
  }  
  if(encoderPos >= MAX_TEMP) 
  {
    myEncoder.setPosition(MAX_TEMP);//1150
    encoderPos = MAX_TEMP;
  }
  beepBuzzer(6250,1);
}
//=======================================================================
//    ENCODER'S DETENT ISR
//=======================================================================
void EncoderClick_ISR() 
{  
  myEncoder.lowLevelClick();
  {
    EEPROM.writeInt(WILL_TEMP_EEPROM_ADDRESS, will_temp);
    EEPROM.writeInt(ENCODER_EEPROM_ADDRESS, encoderPos);
    myEncoder.setPosition(encoderPos);
    memWrite = true;
    memNoWrite = false;  
    beepBuzzer(6250,80);
  }  
}
//=======================================================================
//    TIMER 1 ISR
//=======================================================================
void timer1_ISR()
{
  Timer1.detachInterrupt();
  state =!state;
  switch(heater)
  {
    case HIGH:
      digitalWrite(HEAT_LED, state);
    break;
    case LOW:
       digitalWrite(HEAT_LED, LOW);
    break;  
  }
  if (digitalRead(STANDBYin) == LOW) standby_act = true;
  else standby_act = false;
  Timer1.attachInterrupt( timer1_ISR );
}
//=======================================================================
//    END OF FILE
//=======================================================================
